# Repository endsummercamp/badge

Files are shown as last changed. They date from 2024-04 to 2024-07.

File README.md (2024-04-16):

# Badge

Per l'anno 2024 anche l'End Summer Camp si vuole dotare di un badge interattivo e programmabile, in linea con gli eventi simili internazionali.

## Attuale livello di completamento

- [x] Definizione dei requisiti: 70%
- [ ] Progettazione hardware: 16%
- [ ] Design grafico / artistico: 0%
- [ ] Firmware: 0%

## Obiettivi ad alto livello

- [ ] Il badge non sarà annuale, ma riutilizzabile per tutti gli eventi futuri
- [ ] Il badge dovrà (tentare di) avere un utilità anche al di fuori dell'evento
- [ ] Evitare costi e impatti ambientali inutili, preferire batterie 18650 o stilo per facile riutilizzo, dimensioni ridotte

## Come contribuire

1. Presentarsi nel gruppo telegram https://t.me/endsummercamp
1. L'EDA di riferimento KiCad 8, scaricabile da https://www.kicad.org/
1. Il firmware sarà basato sul linguaggio Rust

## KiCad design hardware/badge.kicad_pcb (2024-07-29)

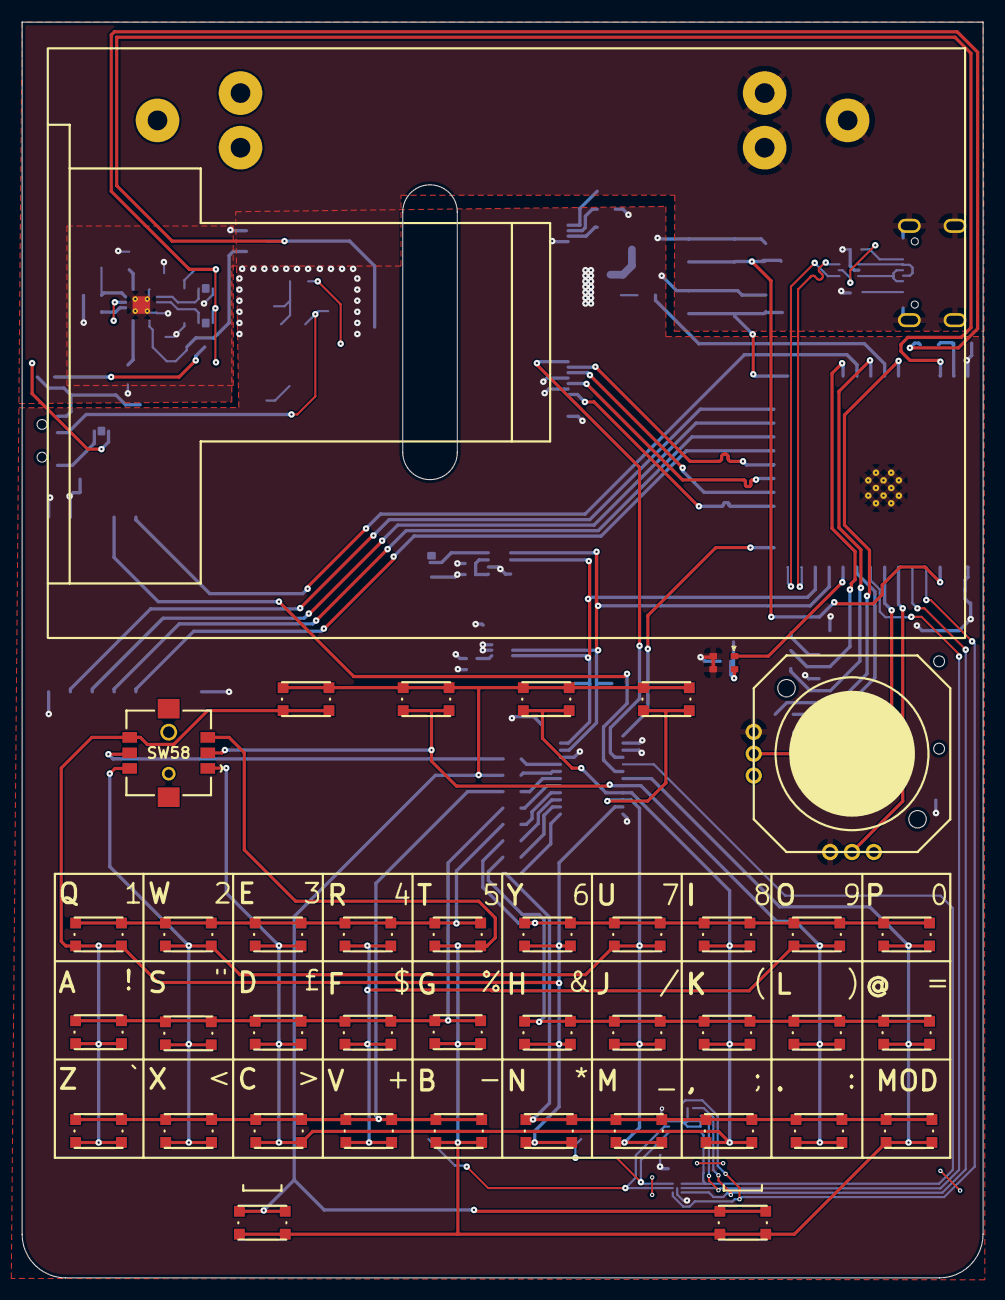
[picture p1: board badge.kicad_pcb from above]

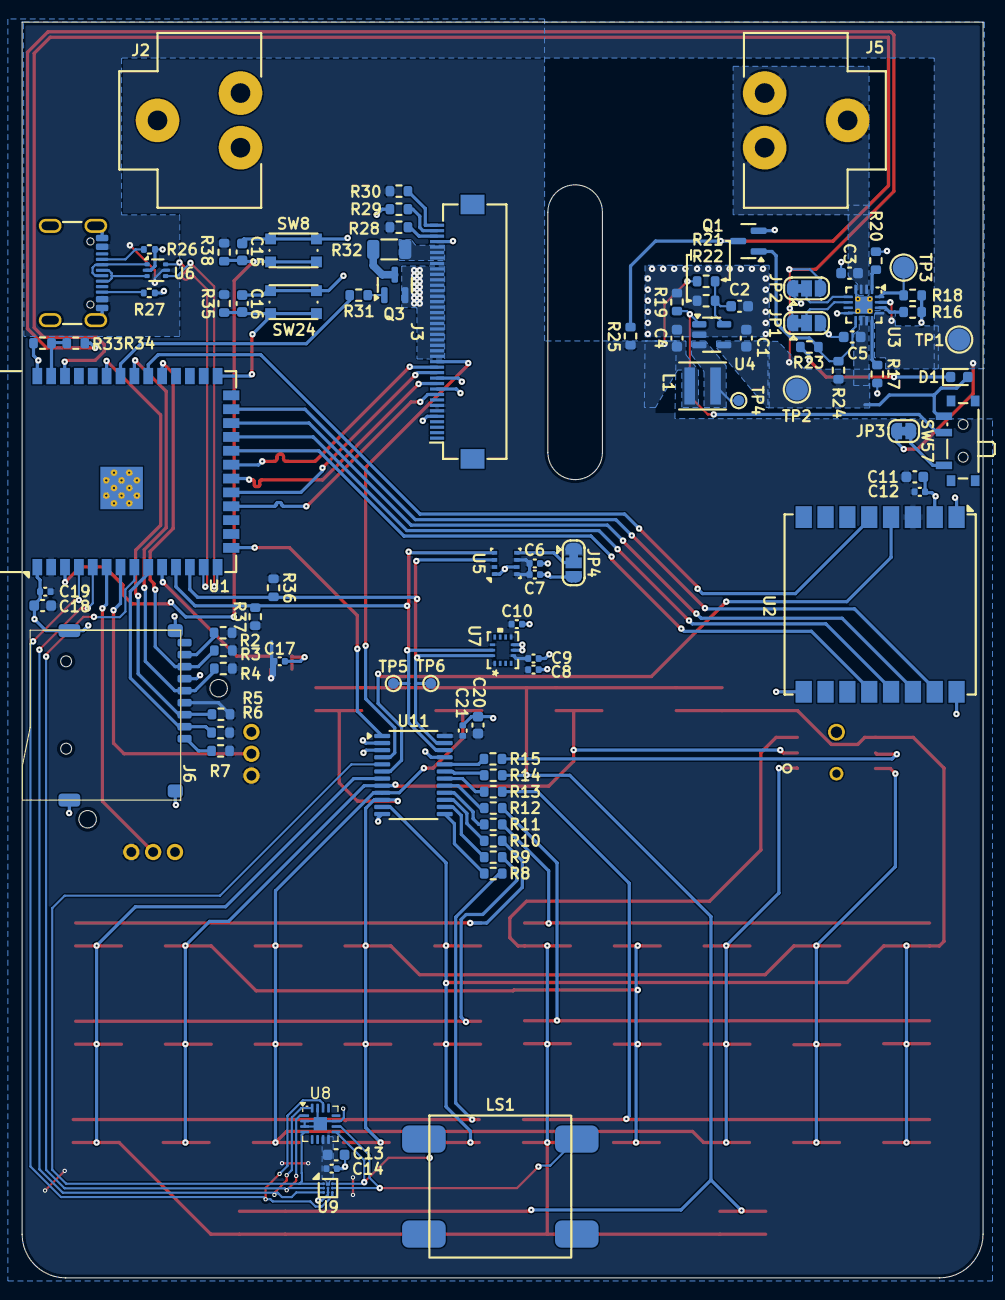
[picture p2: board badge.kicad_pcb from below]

Board: 2 copper layers, 88.0 x 115.0 mm, 131 parts (91 on the bottom side), 85 nets.

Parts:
C1, C3, C5: 4.7uF; C_0603_1608Metric
C2: TBD; C_0603_1608Metric
C4, C11, C13, C15, C16, C18, C20: 10uF; C_0603_1608Metric
C6, C7, C9, C10, C12, C17, C19, C21: 100nF 6.3V; C_0402_1005Metric
C8: 1uF 25V; C_0402_1005Metric
C14: 100nF; C_0402_1005Metric
D1: LED; LED_0603_1608Metric
FID1: DISPLAY; display
J2, J5: MY-18650-01
J3: Conn_01x40; Hirose_FH12-40S-0.5SH_1x40-1MP_P0.50mm_Horizontal
J4: USB_C_Receptacle_USB2.0_14P; USB_C_Receptacle_GCT_USB4105-xx-A_16P_TopMnt_Horizontal
J6: Micro_SD_Card_Det1; TF-01A
JP1: EN1; SolderJumper-3_P1.3mm_Bridged12_RoundedPad1.0x1.5mm
JP2: EN2; SolderJumper-3_P1.3mm_Bridged12_RoundedPad1.0x1.5mm
JP3: Grumpy wifasoi jumper; SolderJumper-2_P1.3mm_Bridged_RoundedPad1.0x1.5mm
JP4: SolderJumper_3_Bridged12; SolderJumper-3_P1.3mm_Bridged12_RoundedPad1.0x1.5mm
L1: 2.2uH; L_Coilcraft_XxL4040
LS1: 8Ω@1W; KLJ-01304T-08R07W
MK1: Microphone_Crystal; microfono
Q1, Q3: AO3400A; SOT-23
R2, R3, R4, R5, R6, R7, R19, R20, R24, R25, R35, R38: 47K; R_0603_1608Metric
R8, R9, R10, R11, R12, R13, R14, R15: 22; R_0603_1608Metric
R16, R28, R29, R30: 0R; R_0603_1608Metric
R17, R36, R37: 1.2K; R_0603_1608Metric
R18: 1.78K; R_0603_1608Metric
R21: 680K; R_0603_1608Metric
R22, R33, R34: 150K; R_0603_1608Metric
R23: 330R; R_0603_1608Metric
R26, R27: 5.1K; R_0402_1005Metric
R31: 100R; R_0603_1608Metric
R32: 12R; R_1206_3216Metric
RV1: R_Potentiometer_Dual_Separate; JOYSTICK_ANALOG_MINITHM
SW1, SW2, SW3, SW4, SW5, SW6, SW7, SW9, SW10, SW11, SW12, SW13, SW14, SW15, SW16, SW17, SW18, SW19, SW20, SW21, SW22, SW23, SW25, SW26, SW27, SW28, SW29, SW30, SW31, SW33, SW34, SW35, SW36, SW37, SW38, SW39: SW_Push; bottonepiccolo_C2888430
SW8: RST; bottonepiccolo_C2888430
SW24: BOOT; bottonepiccolo_C2888430
SW57: MK-12C02-G020; SW_SPDT_PCM12
SW58: SKRHABE010; SKRHABE010_ALPS
TP1, TP2, TP3: TestPoint; TestPoint_Pad_D2.0mm
TP4: TestPoint; TestPoint_Pad_D1.0mm
TP5: SCL; TestPoint_Pad_D1.0mm
TP6: SDA; TestPoint_Pad_D1.0mm
U1: ESP32-S3-WROOM-1
U2: Ai-Thinker-Ra-02; Ai-Thinker-Ra-01-LoRa
U3: BQ24075RGT; VQFN-16-1EP_3x3mm_P0.5mm_EP1.6x1.6mm_ThermalVias
U4: TLV62569DBV; SOT-23-5
U5: BME280; Bosch_LGA-8_2.5x2.5mm_P0.65mm_ClockwisePinNumbering
U6: USBLC6-2P6; SOT-666
U7: BMI270; BMI270_BOS
U8: MAX98357A; TQFN-16-1EP_3x3mm_P0.5mm_EP1.23x1.23mm
U9: MAX98357A; WLP-9_1.448x1.468mm_Layout3x3_P0.4mm_Ball0.27mm_Pad0.25mm
U11: PCA9555PW; TSSOP-24_4.4x7.8mm_P0.65mm

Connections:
+3.3V: C4.1, C6.1, C7.1, C8.1, C9.1, C10.1, C11.1, C12.1, C13.1, C14.1, C17.1, C18.1, C19.1, C20.1, C21.1, J3.6, J3.7, J3.33, J6.4 (VDD), JP4.1 (A), L1.2, MK1.4 (-), R2.1, R3.1, R4.1, R5.1, R6.1, R7.1, R21.1, R25.2, R28.2, R30.1, R35.1, R36.1, R37.1, R38.1, RV1.1, RV1.4, U1.2 (3V3), U2.3 (VDD), U5.2 (CSB), U5.6 (VDDIO), U5.8 (VDD), U7.1 (SDO), U7.5 (VDDIO), U7.8 (VDD), U7.12 (CSB), U8.7 (VDD), U8.8 (VDD), U9.A2 (VDD), U11.24 (VDD)
/AUDIO.BCLK: U1.5 (IO5), U8.16 (BCLK), U9.C1 (BCLK)
/AUDIO.LRCLK: U1.4 (IO4), U8.14 (LRCLK), U9.C3 (LRCLK)
/AUDIO.SD: U1.8 (IO15), U8.1 (DIN), U9.B1 (DIN)
/LCD.CLK: J3.11, U1.20 (IO12)
/LCD.CS: J3.9, U1.18 (IO10)
/LCD.MISO: J3.14, U1.21 (IO13)
/LCD.MOSI: J3.13, U1.19 (IO11)
/LORA.CLK: U1.22 (IO14), U2.12 (SCK)
/LORA.CS: U1.25 (IO48), U2.15 (~NSS)
/LORA.MISO: U1.23 (IO21), U2.13 (MISO)
/LORA.MOSI: U1.24 (IO47), U2.14 (MOSI)
/audio/MUTE: U8.4 (~SD_MODE), U9.A1 (~SD_MODE), U11.5 (IO0_1)
/imu/SCL: R37.2, TP5.1, U1.11 (IO18), U5.4 (SCK), U7.13 (SCX), U11.22 (SCL)
/imu/SDA: R36.2, TP6.1, U1.12 (IO8), U5.3 (SDI), U7.14 (SDX), U11.23 (SDA)
/keyboard/IO_IRQ: U1.15 (IO3), U11.1 (~INT)
/keyboard/LCD_RESET: J3.15, U11.4 (IO0_0)
/keyboard/LORA_CE: U2.4 (~RESET), U11.6 (IO0_2)
/lcd/BACKLIGHT: R31.1, U1.34 (IO41)
/lcd/IM0: J3.38, R28.1
/lcd/IM1: J3.39, R29.2
/lcd/IM2: J3.40, R30.2
/lcd/LEDK: J3.34, J3.35, J3.36, R32.2
/mcu/BOOT: C16.1, R35.2, SW24.2, U1.27 (IO0)
/mcu/CHG: Q1.3 (D), R25.1, U1.38 (IO2)
/mcu/LORA_IRQ: U1.32 (IO39), U2.5 (DIO0)
/mcu/MIC: MK1.1 (+), U1.10 (IO17)
/mcu/RST: C15.1, R38.2, SW8.2, U1.3 (EN)
/mcu/SD_CLK: J6.5 (CLK), R4.2, U1.33 (IO40)
/mcu/SD_CMD: J6.3 (CMD), R5.2, U1.35 (IO42)
/mcu/SD_CS: J6.2 (DAT3/CD), R6.2, U1.9 (IO16)
/mcu/SD_D0: J6.7 (DAT0), R3.2, U1.31 (IO38)
/mcu/USB_D+: U1.14 (IO20), U6.4 (I/O2)
/mcu/USB_D-: U1.13 (IO19), U6.6 (I/O1)
/mcu/VBAT_DIV2: R33.1, R34.2, U1.39 (IO1)
/mcu/XOUT: RV1.5, U1.7 (IO7)
/mcu/YOUT: RV1.2, U1.6 (IO6)
/power/EN1: JP1.2 (C), U3.6 (EN1)
/power/EN2: JP2.2 (C), U3.5 (EN2)
/power/ISET: R18.1, TP3.1, U3.16 (ISET)
/power/~CHG: Q1.1 (G), R23.1, R24.1, U3.9 (~CHG)
GND: C1.2, C2.2, C3.2, C4.2, C5.2, C6.2, C7.2, C8.2, C9.2, C10.2, C11.2, C12.2, C13.2, C14.2, C15.2, C16.2, C17.2, C18.2, C19.2, C20.2, C21.2, J2.1, J3.5, J3.10, J3.12, J3.16, J3.17, J3.18, J3.19, J3.20, J3.21, J3.22, J3.23, J3.24, J3.25, J3.26, J3.27, J3.28, J3.29, J3.30, J3.31, J3.32, J3.37, J4.A1 (GND), J4.A12 (GND), J4.B1 (GND), J4.B12 (GND), J4.S1 (SHIELD), J6.6 (VSS), J6.10 (SHIELD), JP1.3 (B), JP2.1 (A), JP4.3 (B), MK1.2 (-), MK1.3 (-), Q1.2 (S), Q3.2 (S), R16.2, R17.2, R18.2, R19.1, R20.2, R22.2, R26.2, R27.2, R29.1, R33.2, RV1.3, RV1.6, SW8.1, SW24.1, U1.1 (GND), U1.40 (GND), U1.41 (GND), U2.1 (GND), U2.2 (GND), U2.9 (GND), U2.16 (GND), U3.4 (~CE), U3.8 (VSS), U3.17 (VSS), U4.2 (GND), U5.1 (GND), U5.7 (GND), U6.2 (GND), U7.6 (GNDIO), U7.7 (GND), U8.2 (GAIN_SLOT), U8.3 (GND), U8.11 (GND), U8.15 (GND), U8.17 (PAD), U9.B2 (GAIN_SLOT), U9.C2 (GND), U11.2 (A1), U11.3 (A2), U11.12 (VSS), U11.21 (A0)
unnamed: D1.1 (K), R23.2
unnamed: J4.A5 (CC1), R26.1
unnamed: J4.B5 (CC2), R27.1
unnamed: J4.A6 (D+), J4.B6 (D+), U6.3 (I/O2)
unnamed: J4.A7 (D-), J4.B7 (D-), U6.1 (I/O1)
unnamed: C3.1, J5.1, U3.2 (BAT), U3.3 (BAT)
unnamed: J6.8 (DAT1), R2.2
unnamed: J6.1 (DAT2), R7.2
unnamed: JP3.2 (B), SW57.1 (A)
unnamed: JP4.2 (C), U5.5 (SDO)
unnamed: Q3.3 (D), R32.1
unnamed: Q3.1 (G), R31.2
unnamed: R8.2, SW1.1, SW9.1, SW17.1, SW25.1, SW33.1
unnamed: R9.2, SW2.1, SW10.1, SW18.1, SW26.1, SW34.1
unnamed: R10.2, SW3.1, SW11.1, SW19.1, SW27.1, SW35.1
unnamed: R11.2, SW4.1, SW12.1, SW20.1, SW28.1, SW36.1
unnamed: R12.2, SW5.1, SW13.1, SW21.1, SW29.1, SW37.1
unnamed: R13.2, SW6.1, SW14.1, SW22.1, SW30.1, SW38.1
unnamed: R14.2, SW7.1, SW15.1, SW16.1, SW23.1, SW31.1, SW39.1
unnamed: R15.2, SW58.5
unnamed: R19.2, SW57.2 (B), U4.1 (EN)
unnamed: R17.1, U3.12 (ILIM)
unnamed: R16.1, U3.14 (TMR)
unnamed: R20.1, U3.1 (TS)
unnamed: C2.1, R21.2, R22.1, U4.5 (FB)
unnamed: L1.1, TP4.1, U4.3 (SW)
unnamed: LS1.1, U8.10 (OUTN), U9.B3 (OUTN)
unnamed: LS1.2, U8.9 (OUTP), U9.A3 (OUTP)
unnamed: SW16.2, SW33.2, SW34.2, SW35.2, SW36.2, SW37.2, SW38.2, SW39.2, SW58.3, U11.7 (IO0_3)
unnamed: SW25.2, SW26.2, SW27.2, SW28.2, SW29.2, SW30.2, SW31.2, SW58.2, U11.8 (IO0_4)
unnamed: SW17.2, SW18.2, SW19.2, SW20.2, SW21.2, SW22.2, SW23.2, SW58.1, U11.9 (IO0_5)
unnamed: SW9.2, SW10.2, SW11.2, SW12.2, SW13.2, SW14.2, SW15.2, SW58.4, U11.10 (IO0_6)
unnamed: SW1.2, SW2.2, SW3.2, SW4.2, SW5.2, SW6.2, SW7.2, SW58.6, U11.11 (IO0_7)
unnamed: R8.1, U11.13 (IO1_0)
unnamed: R9.1, U11.14 (IO1_1)
unnamed: R10.1, U11.15 (IO1_2)
unnamed: R11.1, U11.16 (IO1_3)
unnamed: R12.1, U11.17 (IO1_4)
unnamed: R13.1, U11.18 (IO1_5)
unnamed: R14.1, U11.19 (IO1_6)
unnamed: R15.1, U11.20 (IO1_7)
VSYS: C1.1, C5.1, D1.2 (A), JP1.1 (A), JP2.3 (B), R24.2, R34.1, SW57.3 (C), TP2.1, U3.10 (OUT), U3.11 (OUT), U4.4 (VIN)
VUSB: J4.A4 (VBUS), J4.A9 (VBUS), J4.B4 (VBUS), J4.B9 (VBUS), JP3.1 (A), TP1.1, U3.13 (IN), U3.15 (SYSOFF), U6.5 (VBUS)

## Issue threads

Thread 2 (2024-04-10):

Porte di espansione

Kezii, 2024-04-10:
SAO

https://badge.team/docs/standards/sao/

EMF / hexpansions

https://github.com/emfcamp/badge-2024-hardware/tree/main/hexpansion

https://tildagon.badge.emfcamp.org/#hexpansions

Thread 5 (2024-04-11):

Licenza

wifasoi, 2024-04-11:
Prima che sia troppo tardi.. scegliamo una licenza per la repo.
MIT? OHL? WTFPL?

Kezii, 2024-04-11:
https://github.com/badgeteam/mch2022-badge-hardware/blob/master/LICENSE

Closed 2024-04-12.

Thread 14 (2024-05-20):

Display reset tied to GND

wifasoi, 2024-05-20:
The reset was incorrectly tied in to ground here
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

Another point, What the datasheet says about unused pin? it's ok to tie them directly to ground (I think yes)

Closed 2024-05-22.

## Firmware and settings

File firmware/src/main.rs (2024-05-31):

use display_interface_spi::SPIInterface;

use esp_idf_hal::{
    delay::Ets,
    gpio::{InputPin, Output, OutputPin, PinDriver},
    ledc::{LedcChannel, LedcTimer},
    peripheral::Peripheral,
    prelude::*,
    spi::{Dma, SpiAnyPins, SpiDeviceDriver, SpiDriver, SpiDriverConfig},
};

use esp_idf_hal::peripherals;
use log::info;

use crate::display_driver::FramebufferTarget;

/*

#define TFT_WIDTH  320
#define TFT_HEIGHT 480

#define TFT_MISO 18
#define TFT_MOSI 7
#define TFT_SCLK 10
#define TFT_CS   9  // Chip select control pin
#define TFT_DC   8  // Data Command control pin
#define TFT_RST  19

*/

mod display_driver;

#[allow(clippy::too_many_arguments)]
pub fn prepare_display<SPI: SpiAnyPins>(
    spi: impl Peripheral<P = SPI> + 'static,
    sdo: impl Peripheral<P = impl OutputPin> + 'static,
    sdi: Option<impl Peripheral<P = impl InputPin> + 'static>,
    sclk: impl Peripheral<P = impl OutputPin> + 'static,
    cs: Option<impl Peripheral<P = impl OutputPin> + 'static>,
    rst: impl Peripheral<P = impl OutputPin> + 'static,
    dc: impl Peripheral<P = impl OutputPin> + 'static,
    bl: impl Peripheral<P = impl OutputPin> + 'static,
    ledc_timer: impl Peripheral<P = impl LedcTimer> + 'static,
    ledc_channel: impl Peripheral<P = impl LedcChannel> + 'static,
) -> display_driver::ST7789<
    SPIInterface<
        SpiDeviceDriver<'static, SpiDriver<'static>>,
        PinDriver<'static, impl OutputPin, Output>,
    >,
    esp_idf_hal::gpio::PinDriver<'static, impl OutputPin, esp_idf_hal::gpio::Output>,
    esp_idf_hal::gpio::PinDriver<'static, impl OutputPin, esp_idf_hal::gpio::Output>,
> {
    let config = esp_idf_hal::spi::config::Config::new()
        .baudrate(20.MHz().into())
        .data_mode(esp_idf_hal::spi::config::MODE_0)
        .queue_size(1);
    let device = SpiDeviceDriver::new_single(
        spi,
        sclk,
        sdo,
        sdi,
        cs,
        &SpiDriverConfig::new().dma(Dma::Auto(4096)),
        &config,
    )
    .unwrap();

    let pin_dc = PinDriver::output(dc).unwrap();

    let spi_interface = SPIInterface::new(device, pin_dc);

    // let ledc_config = esp_idf_svc::hal::ledc::config::TimerConfig::new().frequency(25.kHz().into());
    // let timer = LedcTimerDriver::new(ledc_timer, &ledc_config).unwrap();

    // let backlight_pwm = LedcDriver::new(ledc_channel, timer, bl).unwrap();
    // backlight_pwm.set_duty(backlight_pwm.get_max_duty()).unwrap();

    let rst_pin = PinDriver::output(rst).unwrap();
    let bl_pin = PinDriver::output(bl).unwrap();

    display_driver::ST7789::new(spi_interface, Some(rst_pin), Some(bl_pin))
}

fn main() {
    // It is necessary to call this function once. Otherwise some patches to the runtime
    // implemented by esp-idf-sys might not link properly. See https://github.com/esp-rs/esp-idf-template/issues/71
    esp_idf_svc::sys::link_patches();

    // Bind the log crate to the ESP Logging facilities
    esp_idf_svc::log::EspLogger::initialize_default();

    // Initialize the peripherals
    let peripherals = peripherals::Peripherals::take().unwrap();

    log::info!("hello");

    let mut display = prepare_display(
        peripherals.spi2,
        peripherals.pins.gpio13,
        Some(peripherals.pins.gpio1),
        peripherals.pins.gpio14,
        Some(peripherals.pins.gpio10),
        peripherals.pins.gpio11,
        peripherals.pins.gpio12,
        peripherals.pins.gpio15,
        peripherals.ledc.timer0,
        peripherals.ledc.channel0,
    );

    info!("Display prepared");

    let mut delay = Ets;

    display.hard_reset(&mut delay).unwrap();
    display.init(&mut delay).unwrap();

    log::info!("Display initialized");

    const W: usize = 60;
    const H: usize = 60;

    display
        .set_address_window(10, 10, 9 + W as u16, 10 + H as u16)
        .unwrap();

    let mut raw_framebuffer_0 = [0u8; W * H * 3];

    for (x, y) in (0..W).flat_map(|x| (0..H).map(move |y| (x, y))) {
        let i = y * W + x;

        match x {
            0..=20 => {
                raw_framebuffer_0[i * 3] = 0;
                raw_framebuffer_0[i * 3 + 1] = 255;
                raw_framebuffer_0[i * 3 + 2] = 0;
            }
            21..=40 => {
                raw_framebuffer_0[i * 3] = 255;
                raw_framebuffer_0[i * 3 + 1] = 255;
                raw_framebuffer_0[i * 3 + 2] = 255;
            }
            41..=60 => {
                raw_framebuffer_0[i * 3] = 255;
                raw_framebuffer_0[i * 3 + 1] = 0;
                raw_framebuffer_0[i * 3 + 2] = 0;
            }
            _ => {
                raw_framebuffer_0[i * 3] = 255;
                raw_framebuffer_0[i * 3 + 1] = 255;
                raw_framebuffer_0[i * 3 + 2] = 255;
            }
        }
    }

    loop {
        display
            .eat_framebuffer(raw_framebuffer_0.as_slice())
            .unwrap();
    }
}

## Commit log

2024-04-10 move hw in subdirectory
    [badge.kicad_pcb, badge.kicad_sch, keyboard.kicad_sch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]
2024-04-10 add lcd sch
    [badge.kicad_sch, lcd.kicad_sch, mcu.kicad_sch]
2024-04-11 Add the battery charger
    This commit will remove the old battery switching logic, and replace it
    with a BQ24075.
    Some more info are required, so the component that need a value are marked as TBD
    [power.kicad_sch]
2024-04-16 add ch340g
    [mcu.kicad_sch]
2024-04-16 chg pin
    [mcu.kicad_sch, power.kicad_sch]
2024-04-16 fix ch340
    [mcu.kicad_sch]
2024-04-16 keyboard schematic
    [keyboard.kicad_sch, mcu.kicad_sch]
2024-04-17 Make the badge power on on usb connected
    Fix charge led polarity :D
    Isolate more the CHG signal from the BQ24075
    [power.kicad_sch]
2024-04-17 rename power symbols, power switch on EN pin instead of VIN
    [mcu.kicad_sch, power.kicad_sch]
2024-05-01 remove ch340
    [badge.kicad_sch, keyboard.kicad_sch, lcd.kicad_sch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]
2024-05-05 update usb port, esd, lcsc
    [keyboard.kicad_sch, lcd.kicad_sch, mcu.kicad_sch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]
2024-05-05 remove global labels
    [badge.kicad_sch, keyboard.kicad_sch, mcu.kicad_sch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]
2024-05-05 en pullup
    [mcu.kicad_sch]
2024-05-05 add imu BMI270
    [badge.kicad_sch, imu.kicad_sch, mcu.kicad_sch]
2024-05-07 add bme280
    [badge.kicad_sch, imu.kicad_sch, keyboard.kicad_sch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]
2024-05-07 set footprints, some lcsc codes
    [keyboard.kicad_sch, mcu.kicad_sch, power.kicad_sch]
2024-05-14 Initial schema of LCD interface
    [badge.kicad_sch, lcd.kicad_sch]
2024-05-16 lcd wires, wire direction
    [badge.kicad_sch, imu.kicad_sch, keyboard.kicad_sch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]
2024-05-16 battery voltage divider
    [badge.kicad_sch, mcu.kicad_sch, power.kicad_sch]
2024-05-16 Calculate approximate value of LED resistor
    [lcd.kicad_sch]
2024-05-17 Fix resistor value, fix error in schematic
    Pin 37 was incorrectly bunched with the backlight LED cathodes, but is
    actually a GND pin.
    [lcd.kicad_sch]
2024-05-18 display, switches, (switch)joystick footprint
    [badge.kicad_pcb, keyboard.kicad_sch]
2024-05-18 joystick collegato, tastiera aggiornata, modulo lora, layout preliminare
    [badge.kicad_pcb, badge.kicad_sch, keyboard.kicad_sch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]
2024-05-18 move voltage divider from bat to vsys
    [power.kicad_sch]
2024-05-18 Calculate the resistor values for the BMS
    [power.kicad_sch]
2024-05-18 use AO3400A in place of the npn
    [keyboard.kicad_sch, lcd.kicad_sch, power.kicad_sch]
2024-05-18 do not use gpio 45 and 46
    [mcu.kicad_sch]
2024-05-18 add boot button
    [mcu.kicad_sch]
2024-05-18 Add audio subsystem
    This adds a speaker and an I2s DAC+amplifier based on MAX98357A
    [badge.kicad_sch, mcu.kicad_sch]
2024-05-18 Add footprint for the speaker
    As the datashet is a bit shite, we need to check the footprint
    if we stai with the speaker i selected.
    [audio.kicad_sch]
2024-05-19 Fix pin mapping, pin 3/4 are now named "NC"
2024-05-19 Fix gain selector resistor footprint
    [audio.kicad_sch, mcu.kicad_sch]
2024-05-19 keyboard demo
    [badge.kicad_pcb]
2024-05-19 add PCA9555PW io expander
    [badge.kicad_sch, mcu.kicad_sch]
2024-05-19 group things in layout
    [badge.kicad_pcb]
2024-05-20 fix sda scl
    [mcu.kicad_sch]
2024-05-20 remove lcd reset short circuit to gnd
    [lcd.kicad_sch]
2024-05-21 Bms routing (#16)
    Routhe BMS subsystem
    Fix the JP1 and JP2 power net
    [badge.kicad_pcb, power.kicad_sch]
2024-05-22 Route the audio subsystem
    Fix BMS routing
    Remove audio gain selection, to relax routing
    Add DRC rule for JLC
    Add custom rule for Audio BGA routing
    [audio.kicad_sch, badge.kicad_pcb, badge.kicad_sch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]
2024-05-23 Start Routing of power subsystem
    Start routing of lcd and sd card, only for checking if pin swaps are
    needed
    [badge.kicad_pcb]
2024-05-26 add adafruit joystick
    [audio.kicad_sch, badge.kicad_pcb, badge.kicad_sch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]
2024-05-26 remove mux, use i2c expander for keyboard
    [badge.kicad_pcb, badge.kicad_sch, keyboard.kicad_sch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]
2024-05-26 reorganize keyboard buttons for layout
    [badge.kicad_pcb]
2024-05-26 add (analog) mems microphone
    [lcd.kicad_sch, mcu.kicad_sch]
2024-05-27 Add MY-18650-01 footprint and 3d model
    [MY-18650-01.FCStd, MY-18650-01.step, audio.kicad_sch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]
2024-05-27 Move battery on top
    [badge.kicad_pcb]
2024-05-28 Create a preliminary routing
    Disconnect the LORA module from the lcd bus
    Add netclass and lenght matching rule for the LCD signals
    Use Bus for spi syglas for easy netclass association
    Remove cutaway jumper for the io expansions, and hardcode the address
    Routed the keyboard matrix
    Change the LCD resistor to 1202
    Fix the0Ohm resistor footprint
    [audio.kicad_sch, badge.kicad_pcb, badge.kicad_sch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]
2024-05-28 draw the italian flag on lcd rgb888 🫡
2024-05-29 Move usb to the opposite side of the PCB
    Change the lcd SPI pins and use ones dirrectly atatched to SPI2
    Lengh tune the LCD spi line and USB
    [badge.kicad_pcb, badge.kicad_sch, lcd.kicad_sch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]
2024-05-29 Route I2C bus
    Add decoupling capacitors to esp32 and io expandes
    [badge.kicad_pcb, keyboard.kicad_sch, mcu.kicad_sch]
2024-05-29 Add lora module 3d model
    [badge.kicad_pcb, ra02.FCStd, ra02.step]
2024-05-30 Cleanup project library
    Add hexpansion connector symbol, footprint and 3d
    [audio.kicad_sch, badge.kicad_pcb, keyboard.kicad_sch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]
2024-05-31 [firmware] change from esp32-c3 to esp32-s3
2024-05-31 Add button 3D models
    [badge.kicad_pcb]
2024-05-31 Add alps joystic 3d model
    [badge.kicad_pcb]
2024-05-31 Add analog joystick 3D model
    [badge.kicad_pcb]
2024-06-04 Add sdcard fooprint
    Remove io expander
    Reorganize a bit the mcu schematic
    Routed audio
    Routed lora
    Partial pin swapping of esp32 for facilitating routing
    [audio.kicad_sch, badge.kicad_pcb, badge.kicad_sch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]
2024-06-05 Route all board
    Fix CS missing for SD card
    Add IMU symbol and footprint to the project lib
    Finish esp32 pinswaps
    Move non critical signals to the keyboard IO expander
    Add power flag symbols
    Fix Dpad pin type
    Fix IMU pin type
    [audio.kicad_sch, badge.kicad_pcb, badge.kicad_sch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]
2024-06-06 Associate all LCSC component
    Change sdcard pullup resistor to 47K
    Center main schematic
    [audio.kicad_sch, badge.kicad_pcb, badge.kicad_sch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]
2024-06-06 Fix via anular ring
    Fix position of colliding components
    Add mic pin 1 marker manually
    [badge.kicad_pcb]
2024-06-11 Fix sd card footprint
    [badge.kicad_pcb]
2024-06-13 Fix mic footprint
    [badge.kicad_pcb]
2024-06-25 Beautified schematic, added I2C addresses
    [audio.kicad_sch, badge.kicad_pcb, imu.kicad_sch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]
2024-07-01 update bom, correct jlcpcb rotation
    [audio.kicad_sch, badge.kicad_pcb, imu.kicad_sch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]
2024-07-02 Fix rotation and position offset of components
    Fix lora module rotation
    Fix esp32 module position offset
    Fix sd card position offset
    [audio.kicad_sch, badge.kicad_pcb, badge.kicad_sch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]
2024-07-05 Fix audio chip power pin in schematic
    Add the motherfucker in project library
    [audio.kicad_sch]
2024-07-22 add joystick lcsc code
    [badge.kicad_pcb]
2024-07-22 add joystick lcsc code, for real
    [mcu.kicad_sch]
2024-07-25 fix lcsc code for fpc (wrong but somewhat compatible footprint)
    [badge.kicad_pcb, lcd.kicad_sch, power.kicad_sch]
2024-07-25 remove references from front silkscreen
    [badge.kicad_pcb]
2024-07-25 dual footprint for audio amp
    [audio.kicad_sch, badge.kicad_pcb]
2024-07-29 update lcsc codes to use (new?) basic components
    [audio.kicad_sch, badge.kicad_pcb, keyboard.kicad_sch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]
